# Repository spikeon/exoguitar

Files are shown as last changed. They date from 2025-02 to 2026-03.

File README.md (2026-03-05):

# ExoGuitar
This is the Repo for the ExoGuitar project

> **Note:** The file `README.md` in the repo root is **generated** from this template by `npm run generate-json-files`. Do not edit `README.md` by hand—edit `README.template.md` and the script will regenerate the links section.

## Documentation

- [Assembly Documentation](./ASSEMBLY.md)
- [How to Contribute](./CONTRIBUTING.md)

## MakerWorld Listings

This is a MakerWorld exclusive project; so all print profiles are hosted and maintained there.

[MakerWorld Collection](https://makerworld.com/en/collections/4170197-exoguitar)

## Makerworld Links 

### Back

- Generator - Coming soon to MakerWorld!
- Screw On - Coming soon to MakerWorld!
- Slide In - Coming soon to MakerWorld!

### Bridge

- [Alnicov 6 Strings Saddle Headless](https://makerworld.com/en/models/946216-exoguitar-bridge-alnicov-saddle-headless)
- [Bearing Bridge](https://makerworld.com/en/models/969432-exoguitar-bearing-bridge)
- [Headless Bridge Plate](https://makerworld.com/en/models/988538-exoguitar-headless-bridge-plate)
- OVSAL Headless Bridge Plate - Coming soon to MakerWorld!
- Telecaster Plate - Coming soon to MakerWorld!
- Thru-Body Bridge Plate - Bearing Bridge - Coming soon to MakerWorld!
- Thru-Body Bridge Plate - Tune-O-matic - Coming soon to MakerWorld!
- [Tremelo](https://makerworld.com/en/models/1288644)
- [Tune O' Matic - Multi Plate](https://makerworld.com/en/models/1288679-exoguitar-saddle-tune-o-matic#profileId-1318404)
- Tune O' Matic - Single Plate - Coming soon to MakerWorld!

### Face Plates

- [Acoustic](https://makerworld.com/en/models/1155233-exoguitar-acoustic-core)
- [Dual Humbucker](https://makerworld.com/en/models/1155233-exoguitar-acoustic-core)
- Dual P90 - Coming soon to MakerWorld!
- [Single Humbucker - Bridge](https://makerworld.com/en/models/1155233-exoguitar-acoustic-core)
- [Single Humbucker - Centered](https://makerworld.com/en/models/1155233-exoguitar-acoustic-core)
- [SSS](https://makerworld.com/en/models/1155233-exoguitar-acoustic-core)
- [Telecaster](https://makerworld.com/en/models/1155233-exoguitar-acoustic-core)

### Head

- Arasaka - Coming soon to MakerWorld!
- [Arrow](https://makerworld.com/en/models/977949-exoguitar-head)
- [Classical](https://makerworld.com/en/models/1158327-exoguitar-classical-head-printed-tuners)
- [Explorer](https://makerworld.com/en/models/1242688-exoguitar-head-explorer)
- [Firebird](https://makerworld.com/en/models/1242697-exoguitar-head-firebird)
- [Headless](https://makerworld.com/en/models/977972-exoguitar-headless-adjustable-nut)
- Headless - OVSAL String Lock - Coming soon to MakerWorld!
- Headless - String Lock - Coming soon to MakerWorld!
- Headless v2 - Coming soon to MakerWorld!
- [Jack's Son](https://makerworld.com/en/models/1223137-exoguitar-head-jack-s-son)
- [King Paul](https://makerworld.com/en/models/1405761-exoguitar-head-king-paul)
- [Less Paul](https://makerworld.com/en/models/1242379-exoguitar-head-less-paul)
- Loop - Coming soon to MakerWorld!
- Sharky - Coming soon to MakerWorld!

### Neck

- Neck v3 - Coming soon to MakerWorld!

### Nut

### Shoulders

- Double Cut - Coming soon to MakerWorld!
- Single Cut - Coming soon to MakerWorld!

### Wing Sets

- Arasaka - Coming soon to MakerWorld!
- [BanjNo](https://makerworld.com/en/models/1158493-exoguitar-wings-banj-no)
- CigTar - Coming soon to MakerWorld!
- [Cyber Butterfly](https://makerworld.com/en/models/946179-exoguitar-cyber-butterfly-wings)
- Explorer - Coming soon to MakerWorld!
- [Firebird](https://makerworld.com/en/models/988586-exoguitar-wings-firebird)
- Heart - Coming soon to MakerWorld!
- Ichiban Ezu - Coming soon to MakerWorld!
- Jack's Son - Coming soon to MakerWorld!
- [Kumiko](https://makerworld.com/en/models/1517226-exoguitar-wings-kumiko)
- [Less Paul](https://makerworld.com/en/models/1158385-exoguitar-wings-less-paul)
- [More Paul](https://makerworld.com/en/models/1162982-exoguitar-wings-more-paul)
- MultiBoard - Coming soon to MakerWorld!
- Plastic X - Coming soon to MakerWorld!
- Portal - Coming soon to MakerWorld!
- [Rich](https://makerworld.com/en/models/1078060-exoguitar-wings-rich)
- Symmertrical Guitar - Coming soon to MakerWorld!
- Training-V - Coming soon to MakerWorld!
- Venom - Coming soon to MakerWorld!
- [Warlock](https://makerworld.com/en/models/1391383-exoguitar-wing-set-warlock)

## Multi-Neck Configuration

The sides of the core are made out of 2020 aluminum extrusion and the core terminates exactly along the edge of it.  It was not intended from the beginning, but it DOES allow you to swap out the 2020 for 2040 aluminum extrusion to attach 2 or more cores together to create multiple neck guitars. 

I haven't made a Wing Set specifically for this purpose yet, but the BC Rich may be a good fit for it.  

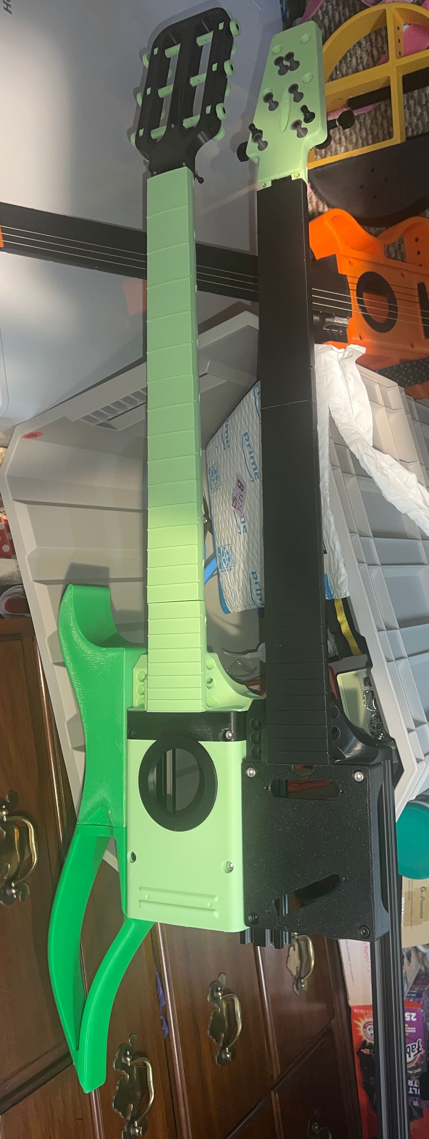
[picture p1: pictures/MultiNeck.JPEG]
Proof of Concept


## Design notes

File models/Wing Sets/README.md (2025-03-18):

# Wing Sets

By default, All wing-sets should only need the hardware listed in the BOM.txt in this folder.  If there is a BOM.txt in the WingSet folder, it is additive to the BOM in this folder.

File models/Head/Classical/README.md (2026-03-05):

# Classical Head

## Plastic Choices

I have now tested this with several types of plastic and can say for certain that you can build functional classical heads out of:
- ABS
- ASA
- PC-ABS
- PLA Tough (at 90% infill and 10 walls)
- PETG-HF (at 90% infill and 10 walls)
- PA

I would still say that you need to be careful regarding the placement of the guitar in relation to the sun if you choose to use PLA Tough or PETG of any form.  

I have had very good results using PLA Tough for the gears.  I did NOT have good results using regular PLA for the gears.  Specifically, I recommend PLA that was made from 3DC870 Resin like [3D Fuel Tough PLA+](https://amzn.to/43JGNtU) for its specific mechanical properties (Special shout out to @nte on the West3D Discord for this).

## To use: 

- Put the string through the hole in the shaft.  If the string can't pass through, loosen the lock knob (the one on the side of the head).  
- Pull the string through the hole until it is taught but not so taught that it could produce a note if plucked.  
- Tighten the Lock Knob until you can no-longer pull or push the string through the hole.  Be careful to not overtighten, as this could lead to the screw cutting the string.  
- Snip off the end of the string.  Do yourself a favor and leave 2-3mm so if you have to remove the string you have a chance of putting it back in. 
- Tighten the tuning knob in the direction that makes the shaft spin so the string wraps over the top of the shaft.  Tighten until the string reaches the desired pitch.  If you are using Nylon Strings, your instrument will not reach a stable tune for a couple of days and you will have to - - repeat this process every few hours; as Nylon Strings have a 2-3 day break in period.  During this time it is important that you tune it every 2-3 hours. 

## Important Note about the printed gears: 

I have decided to deprecate the printed worm gear due to it being too much of a challenge to save $8.

The printed gears are a challenging print and require a 0.2 nozzle.  They are not forgiving.

If you have trouble with the printed gears, you can use [these](https://amzn.to/4l2Nihy) instead.  Glue them to the M2 screw instead of using locktite.  The issue that caused me to remove these from the BOM and design my own printed screws is that the glue doesn't always hold and you may end up having to re-apply glue before you can tune it again, but if for whatever reason you can't get your strings up to tune due to printing defects that'd likely be less of an issue.

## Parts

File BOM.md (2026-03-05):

# Unified BOM

This BOM should contain everything needed to build a single ExoGuitar.  As this will encompass all possible options, there will be left-overs.  If you want to ensure you only buy the necessary parts, feel free to go through each part and compile your own BOM for just the parts you want to build. 

I will first list the items, and then a separate list of links to products, so that I can use bundled items. 

For simplicity, This list only contains suggested hardware.  I will list recommended Guitar Parts at the end, but as they are expensive please make sure that they are part of your build before purchasing.  

## Materials

| Qty | Name |
| :-- | :--- |
| 20  | Screw - Socket Head - M2x6 |
| 6 | Screw - Socket Head - M2x16 |
| 6 | M3 Washer |
| 8 | Screw - Grub - M3x8 |
| 8 | Screw - Flat Head - M3x6 |
| 10  | Screw - Flat Head - M3x10 |
| 10  | Screw - Flat Head - M3x20 |
| 6 | Screw - Flat Head - M3x25 |
| 6 | Screw - Button Head - M3x8 |
| 11  | Screw - Button Head - M3x35 |
| 6 | Screw - Socket Head - M3x10 |
| 5 | Screw - Socket Head - M3x20 |
| 8 | Screw - Socket Head - M3x25 |
| 12  | Screw - Socket Head - M3x40 |
| 2 | Screw - Socket Head - M4x35 |
| 11  | Screw - Button Head - M5x6 |
| 6 | Screw - Button Head - M5x8 |
| 26  | Screw - Button Head - M5x10 |
| 4 | Screw - Button Head - M5x12 |
| 17  | Screw - Button Head - M5x30 |
| 1 | Screw - Socket Head - M5x45 |
| 2 | Screw - Button Head - M6x12 |
| 24  | Nut - Slide In - M3 |
| 60  | Nut - Slide In - M5 |
| 26  | M2x3x3.5 Heat Set Inserts | 
| 2 | M3x4.8x4.6 Flanged Heat Set Inserts |
| 12  | M3x4x4 Heat Set Inserts |
| 49  | M3x4x5 Heat Set Inserts |
| 8 | M4x6x6 Heat Set Inserts | 
| 6 | 3x10x3 V-Bearing |
| 12  | MR128ZZ Bearings |
| 10  | 2mm x 30mm Pin |	
| 10  | 2mm x 60mm Pin |	
| 1 | 2020 Aluminum Extrusion - 500mm |
| 1 | 2020 Aluminum Extrusion - 200mm | 
| 1 | 2020 Aluminum Extrusion - 250mm |
| 1	  | Fret Wire Set |			
| 20  | Prewired SMD Led 0603 |
| 1 | CR2032 Battery | 
| 1	  | 5mmx2mm Slide Switch	| 
| 3	  | Jumper Wire |
| 1	  | CA Glue	|
| 1	  | Super Lube |
| 1 | Locktite Red | 
| 1 | 1m Wire,  24AWG |
| 14  | Screw - Nylon Tipped Set - M3x14 |

## Links

For this list, QTY is the number of the linked product to buy, not the number of individual items needed

### Materials

| Qty | Name | Url | Qty Per Product | Price Per Product | Price  Per Guitar |
| :-- | :--- | :-- | ---: | ---: | ---: |
| 1 | 2020 Aluminum Extrusion - 500mm | [Amazon](https://amzn.to/40dqOAR) | 4 | $30 | $7.50 |
| 1 | 2020 Aluminum Extrusion - 250mm | [Amazon](https://amzn.to/4ig9fHU) | 4 | $16 | $4 |
| 1	  | 2020 Aluminum Extrusion - 200mm | [Amazon](https://amzn.to/4iloM9A) | 4 | $15 | $3.75 |
| 1 | 2mm x 30mm Pin | [Amazon](https://amzn.to/3CVybpb) | 50 | $8.69 | $1.75 |
| 1 | 2mm x 60mm Pin | [Amazon](https://amzn.to/4gU5Ey2) | 50 | $10 | $2 |
| 1 | M3x4.8x4.6 Flanged Heat Set Inserts | [Amazon](https://amzn.to/4kOFT5J) | 20 | $22.86 | $2.29 |
| 1 | M2x3x3.5 Heat Set Inserts | [Amazon](https://amzn.to/4jeeI36) | 110 | $6.59 | $1.56 |
| 1 | M3x4x4 Heat Set Inserts | [Amazon](https://amzn.to/4i5ozHH) | 100 | $7.99 | $0.73 |
| 1 | M3x4x5 Heat Set Inserts | [Amazon](https://amzn.to/4kBjzwc) | 130 | $6.97 | $2.62 |
| 1 | M4x6x6 Heat Set Inserts | [Amazon](https://amzn.to/3WdVVLz) | 110 | $7.99 | $0.58 |
| 1 | Nut - Slide In - M5 | [Amazon](https://amzn.to/4ie0m23) | 100 | $14.59 | $3.50 |
| 1 | Nut - Slide In - M3 | [Amazon](https://amzn.to/3DQQRa3) | 100 | $11.99 | $7.20 |
| 1 | Screw - Socket Head - M2x16 | [Amazon](https://amzn.to/4ij7Lgc) | 100 | $7.16 | $0.42 |
| 1 | Screw - Grub - M3x8 | [Amazon](https://amzn.to/4hqwGht) | 40 | $6.19 | $1.25 |
| 1 | M3 SHCS 6-35 Pack | [Amazon](https://amzn.to/3DBNML3) | N/A | $12.99 | $6.50 |
| 1 | M3 FHCS 4-40 Pack | [Amazon](https://amzn.to/3FM6DDw) | N/A| $18.70 | $9.35 |
| 1 | Screw - Socket Head - M4x35 | [Amazon](https://amzn.to/3DOC3s2) | 50 | $7.68 | $0.30 |
| 1 | Screw - Button Head - M5x6 | [Amazon](https://amzn.to/3FyT36q) | 100 | $8.68 | $0.95 |
| 1 | Screw - Button Head - M5x8 | [Amazon](https://amzn.to/42eKKFG) | 100 | $9.68 | $0.58 |
| 1 | Screw - Button Head - M5x10 | [Amazon](https://amzn.to/41DhzuH) | 100 | $9.96 | $2.60 |
| 1 | Screw - Button Head - M5x30 | [Amazon](https://amzn.to/41upYjY) | 50 | $9.02 | $3.06 |
| 1 | Screw - Socket Head - M5x45 | [Amazon](https://amzn.to/4akIBuH) | 20 | $9.49 | $0.47 |
| 1 | 3x10x3mm V-Bearings | [Amazon](https://amzn.to/4fW4pOq) | 10 | $9.09 | $5.45 |
| 1 | MR128ZZ Bearings | [Amazon](https://amzn.to/3FPtVIE) | 20 | $14.40 | $8.64 |
| 1 | Fret Wire Set | [Amazon](https://amzn.to/4abYcNa) | 1 | $17.49 | $17.49 |
| 1 | Prewired SMD Led 0603 | [Amazon](https://amzn.to/4g1B8SI) | 25 | $13.99 | $11.20 |
| 1 | CA Glue | [Amazon](https://amzn.to/3C5g27S) | N/A | $47.99 | $4.80 |
| 1 | Super Lube | [Amazon](https://amzn.to/3WeCouC) | N/A | $7.97 | $0.80 |
| 1 | CR2032 Battery | [Amazon](https://amzn.to/4aeYF1d) | 4 | $13.19 | $3.30 |
| 1	  | 5mmx2mm Slide Switch | [Amazon](https://amzn.to/4hd0GNI) | 100 | $7.99 | $0.08 |
| 1 | Jumper Wire | [Amazon](https://amzn.to/40c2IXh) | 560 | $9.99 | $0.05 |
| 1 | Locktite Red | [Amazon](https://amzn.to/4iA8NEI) | 100 | $23.20 | $0.23 |
| 1 | Wire | [Amazon](https://amzn.to/41UZiZN) | 91.44 | $26.99 | $0.30 |
| 1 | Screw - Nylon Tipped Set - M3x14 | [Amazon](https://amzn.to/4ecwIJk) | 15 | $8.49 | $0.85 |

#### Totals: 

Before we get to the totals, just a reminder that this document is a One-Size-Fits-All BOM.  If you compiled your own BOM from the individual parts you plan to build with, the price might be far less; depending on the options picked.  In essence, this is the most expensive guitar possible in ExoGuitar.

- Price to buy all of this and build only one: $460
- Price Per Guitar if building many: $120

If we remove the items only needed for the "Luxury features" on the neck (Metal Frets, M2x6 screws, All electronics items from above list) we get a more reasonable result:

- Price to buy all of this and build only one: $370
- Price Per Guitar if building many: $89

### Kits

I currently offer a DIY Kit that includes the above BOM on my Etsy.

[Check it out here!](https://www.etsy.com/listing/4309899889/exoguitar-diy-kit)

I am also in talks with a company about providing these kits for me; which will have a much faster processing time. 

### Hardware

- [Fret Wire Bender](https://amzn.to/3E202E7) - There is a printable one (with its own BOM) in this project [here](./models/Neck/tools/Fret%20Bender/ASSEMBLY.md)
- [Metric Tap Bits](https://amzn.to/41XLL3B)
- [Fanttik E2 Ultra Precision Screwdriver](https://www.amazon.com/dp/B0DSVKLNQR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) - There are a lot of screws in this project.  This helps. 
- [Fanttik T1 Max Soldering Iron](https://www.amazon.com/dp/B0D41ZMDPD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) - This wireless Soldering Iron comes in really handy for soldering parts inside of a guitar. 

### Recommended Guitar Parts
- [Locking Tuning Pegs - 6R](https://amzn.to/4kwxHGX)
- [Locking Tuning Pegs - 3L3R](https://amzn.to/43QKSwm)
- [Single Humbucker Electronics Kit](https://amzn.to/4kV8FkS)
- [Dual Humbucker Electronics Kit](https://amzn.to/4kwyho7)
- [Telecaster Electronics Kit](https://amzn.to/4hj26pr)
- [Tune-O-Matic Bridge](https://amzn.to/4hDBjF1)
- [Piezo Pickups](https://amzn.to/3Xm2SKZ)
- [Nylon Strings](https://amzn.to/3XgaFKf)

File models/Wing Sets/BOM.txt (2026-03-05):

Qty   Name                                 Url                      Optional
  12  Screw - Button Head - M5x10          https://amzn.to/41DhzuH  false
  12  Nut - Slide In - M5                  https://amzn.to/4ie0m23  false
   2  M3x4.8x4.6 Flanged Heat Set Inserts  https://amzn.to/4kOFT5J  false
  10  Screw - Flat Head - M3x10            https://amzn.to/4iCkiM0  false
  10  Screw - Flat Head - M3x20            https://amzn.to/4bVan1y  false
  20  M3x4x5 Heat Set Inserts              https://amzn.to/4kBjzwc  false

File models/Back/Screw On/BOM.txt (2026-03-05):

Qty   Name                      Url                      Optional
   8  Nut - Slide In - M3       https://amzn.to/3DQQRa3  false
   8  Screw - Flat Head - M3x6  https://amzn.to/4bWM7w6  false

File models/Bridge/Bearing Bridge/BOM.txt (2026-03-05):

Qty   Name                         Url                      Optional
   2  M4x6x6 Heat Set Inserts      https://amzn.to/3WdVVLz  false
   5  M3x4x5 Heat Set Inserts      https://amzn.to/4jk12nw  false
   5  Screw - Socket Head - M3x35  https://amzn.to/3C4CAFL  false
   2  Screw - Socket Head - M4x35  https://amzn.to/3DOC3s2  false
   5  Screw - Socket Head - M3x20  https://amzn.to/4gSbS2j  false
   6  Screw - Grub - M3x8          https://amzn.to/4hqwGht  false
   6  3x10x3 V-Bearing             https://amzn.to/4fW4pOq  false
   6  M3x4x5 Heat Set Insert       https://amzn.to/4jk12nw  false
   6  Screw - Button Head - M3x35  https://amzn.to/4a9PA9D  false
   1  Super Lube                   https://amzn.to/3WeCouC  false

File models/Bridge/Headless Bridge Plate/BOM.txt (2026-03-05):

Qty   Name                         Url         Optional
   9  Screw - Button Head - M5x30              false
   9  Nut - Slide In - M5                      false
   6  L Tuning Pegs                            false
  12  Screw - Socket Head - M3x40              false
   6  Screw - Socket Head - M3x10              false
  12  M3x4x5 Heat Set Inserts                  false
   6  M2x3x3 Heat Set Inserts                  false
   2  Screw - Button Head - M5x12              false
   2  Screw - Button Head - M6x12              false

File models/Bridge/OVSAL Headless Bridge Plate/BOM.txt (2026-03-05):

Qty   Name                         Url                      Optional
   1  OVSAL Headless Bridge        https://amzn.to/4navL8k  false
   4  Nut - Slide In - M5          https://amzn.to/3SYdIEF  false
   4  Screw - Socket Head - M5x30  https://amzn.to/3ZFyQDp  false
   4  Screw - Flat Head - M3x16    https://amzn.to/3T1fKnm  false
   4  M3x4x5 Heat Set Inserts      https://amzn.to/45smyBY  false

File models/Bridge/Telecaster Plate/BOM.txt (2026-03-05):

Qty   Name                         Url                      Optional
   1  Telecaster Plate             https://amzn.to/414uZAi  false
   8  Nut - Slide In - M5          https://amzn.to/3SYdIEF  false
   8  Screw - Socket Head - M5x30  https://amzn.to/3ZFyQDp  false
   5  M3x4x5 Heat Set Inserts                               false

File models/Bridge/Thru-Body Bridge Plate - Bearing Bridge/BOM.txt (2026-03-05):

Qty   Name                         Url         Optional
   6  Screw - Button Head - M5x30              false
   6  Nut - Slide In - M5                      false
   6  M4x6x6 Heat Set Insert                   false
   6  M3x4x5 Heat Set Insert                   false

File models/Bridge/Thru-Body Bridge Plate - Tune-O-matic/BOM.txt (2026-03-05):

Qty   Name                         Url                      Optional
   6  Screw - Button Head - M5x30                           false
   6  Nut - Slide In - M5                                   false
   6  M4x6x6 Heat Set Insert                                false
   1  Tune-O-Matic Bridge          https://amzn.to/4hDBjF1  false

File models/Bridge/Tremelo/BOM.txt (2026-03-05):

Qty   Name                         Url                      Optional
   4  Screw - Socket Head - M5x16  https://amzn.to/42s4kyt  false
   4  Screw - Socket Head - M5x30  https://amzn.to/3R20buE  false
   8  Nut - Slide In - M5          https://amzn.to/4hYYDg9  false
   2  M8 Heat Set Inserts          https://amzn.to/3DUSEuV  false
   4  M3x4x5 Heat Set Inserts      https://amzn.to/3YknHHd  false
   1  Tremolo Tailpiece            https://amzn.to/42tQiMK  false
   1  Tune O' Matic Saddle         https://amzn.to/4cgSWJ0  false

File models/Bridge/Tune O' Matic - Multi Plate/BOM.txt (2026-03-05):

Qty   Name                         Url                      Optional
   1  Tune O' Matic Saddle         https://amzn.to/4cgSWJ0  false
   2  M8 Heat Set Inserts          https://amzn.to/3DUSEuV  false
   4  Nut - Slide In - M5          https://amzn.to/4hYYDg9  false
   4  Screw - Socket Head - M5x16  https://amzn.to/42s4kyt  false

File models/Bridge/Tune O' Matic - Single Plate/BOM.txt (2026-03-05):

Qty   Name                         Url                      Optional
   6  Nut - Slide In - M5          https://amzn.to/3SYdIEF  false
   6  Screw - Socket Head - M5x30  https://amzn.to/3ZFyQDp  false
   4  M8 Heat Set Inserts          https://amzn.to/3TV07yg  false

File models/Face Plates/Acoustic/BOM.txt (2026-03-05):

Qty   Name                             Url                      Optional
   1  2020 Aluminum Extrusion - 250mm  https://amzn.to/4ig9fHU  false
   1  2020 Aluminum Extrusion - 200mm  https://amzn.to/4iloM9A  false
   8  Nut - Slide In - M3              https://amzn.to/4i9GfBE  false
   7  Nut - Slide In - M5              https://amzn.to/40tPEOo  false
   3  Screw - Button Head - M5x8       https://amzn.to/4bmHoDI  false
   6  Screw - Button Head - M5x30      https://amzn.to/3D6UoRf  false
   3  Screw - Button Head - M3x8       https://amzn.to/4hWLhlj  false
   6  M3x5x4 Heat Set Inserts          https://amzn.to/4jk12nw  false
   2  Screw - Grub - M3x8              https://amzn.to/3QIKW9T  false
   1  Nylon Strings                    https://amzn.to/3XgaFKf  false
   1  Piezo Pickups                    https://amzn.to/3Xm2SKZ  true
   8  Screw - Flat Head - M3x5         https://amzn.to/43XTCzx  false

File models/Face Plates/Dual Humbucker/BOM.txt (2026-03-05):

Qty   Name                         Url                      Optional
   4  Nut - Slide In - M5          https://amzn.to/4ie0m23  false
   4  Screw - Button Head - M5x30                           false
   1  Electronics Kit                                       false

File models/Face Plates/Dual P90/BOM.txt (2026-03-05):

Qty   Name                         Url                      Optional
   4  Screw - Flat Head - M2.5x45  https://amzn.to/3UN7xnv  false
   4  Nut - Slide In - M5          https://amzn.to/4ie0m23  false
   4  Screw - Button Head - M5x30                           false

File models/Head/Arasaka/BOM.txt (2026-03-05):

Qty   Name                              Url                      Optional
   2  M3x4x5 Heat Set Inserts                                    false
   1  3L3R Tuning Pegs                  https://amzn.to/3Whyrp0  false
   1  Screw - Socket Head - M5x20                                false
   2  Screw - Nylon Tipped Set - M3x14                           false
   1  3mm COB LED lights                https://amzn.to/4kBaCBK  true

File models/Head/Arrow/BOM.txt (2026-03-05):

Qty   Name                         Url                      Optional
   8  M3x4x4 Heat Set Inserts      https://amzn.to/4gSAk3M  false
   1  3L3R Tuning Pegs             https://amzn.to/3Whyrp0  false
   2  Screw - Button Head - M5x12  https://amzn.to/4jeqLxq  false
   1  Screw - Socket Head - M5x45  https://amzn.to/4akIBuH  false
   2  Nut - Slide In - M5          https://amzn.to/40tPEOo  false
   6  Screw - Flat Head - M3x25    https://amzn.to/4acQHW5  false
   2  Screw - Socket Head - M3x25  https://amzn.to/4jePKRd  false
   1  CR2032 Battery               https://amzn.to/4aeYF1d  false
   1  5mmx2mm Slide Switch         https://amzn.to/4hd0GNI  false
   1  Jumper Wire                  https://amzn.to/40c2IXh  false

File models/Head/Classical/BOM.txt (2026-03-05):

Qty   Name                          Url                      Optional
  10  M3x4x4 Heat Set Inserts       https://amzn.to/4gSAk3M  false
   2  Screw - Button Head - M5x12   https://amzn.to/4jeqLxq  false
   1  Screw - Socket Head - M5x45   https://amzn.to/4akIBuH  false
   2  Nut - Slide In - M5           https://amzn.to/40tPEOo  false
   8  Screw - Socket Head - M3x25   https://amzn.to/4jePKRd  false
   6  Screw - Socket Head - M2x20   https://amzn.to/4ij7Lgc  false
   6  M3 Washer                     https://amzn.to/3ETb4fq  false
  12  MR128ZZ Bearings              https://amzn.to/4kudK3t  false
   6  2mmx6mmx8mm Nylon Worm Gears  https://amzn.to/4hxKhD5  false
   6  M2x3x3 Heat Set Inserts       https://amzn.to/4iAqwMw  false

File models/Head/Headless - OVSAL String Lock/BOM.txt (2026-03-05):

Qty   Name                                             Url                      Optional
   1  OVSAL String Lock                                https://amzn.to/4kUiW0v  false
   4  Screw - Flat Head - M3x25                        https://amzn.to/3ZFr24q  false
   6  M3x4x5 Heat Set Inserts https://amzn.to/45smyBY                           false
   2  Screw - Set - M3x16                              https://amzn.to/467d9js  false
   1  Screw - Socket Head - M5x20                      https://amzn.to/4lfbc8V  false

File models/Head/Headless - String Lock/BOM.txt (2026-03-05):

Qty   Name                         Url                                                                                                        Optional
  14  https://amzn.to/4ecwIJk                                                                                                                 false
  14  M3x4x5 Heat Set Inserts      https://amzn.to/45smyBY                                                                                    false
  12  6x2mm Magnets                https://amzn.to/4njDvFh                                                                                    false
   9  BT3x18 Screws                https://us.store.bambulab.com/products/bt3-socket-head-cap-self-tapping-screws-shcs-new?id=42382271774856  false
   1  Screw - Socket Head - M5x20  https://amzn.to/4lfbc8V                                                                                    false

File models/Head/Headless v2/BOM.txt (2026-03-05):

Qty   Name                         Url                                                                                                        Optional
   8  M3x5x3 Heat Set Inserts      https://amzn.to/3IVU5Lx                                                                                    false
   2  Screw - Grub - M3x16         https://amzn.to/4lZ64GS                                                                                    false
   1  BT3x6                        https://us.store.bambulab.com/products/bt3-socket-head-cap-self-tapping-screws-shcs-new?id=42382271578248  false
   2  BT3x20                       https://us.store.bambulab.com/products/bt3-socket-head-cap-self-tapping-screws-shcs-new?id=42382271807624  false
   1  Screw - Button Head - M6x20  https://amzn.to/4l5QsA0                                                                                    false

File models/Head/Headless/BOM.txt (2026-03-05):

Qty   Name                         Url                      Optional
   8  M3x4x4 Heat Set Inserts      https://amzn.to/4gSAk3M  false
   3  Screw - Button Head - M5x6   https://amzn.to/4jeqLxq  false
   1  Screw - Button Head - M5x12  https://amzn.to/4jeqLxq  false
   3  Nut - Slide In - M5          https://amzn.to/40tPEOo  false
   2  Screw - Socket Head - M3x25  https://amzn.to/4jePKRd  false

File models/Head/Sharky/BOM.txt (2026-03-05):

Qty   Name                         Url                      Optional
   3  M3x5x4 Heat Set Inserts      https://amzn.to/4qBGwBF  false
   1  6L Tuning Pegs               https://amzn.to/3N1Ocyq  false
   1  Screw - Socket Head - M6x20  https://amzn.to/4qxr8Gc  false
   2  Screw - Grub - M3x16         https://amzn.to/491vPSP  false

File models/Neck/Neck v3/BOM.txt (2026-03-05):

Qty   Name                         Url                      Optional
   2  M3x500 Threaded Rod          https://amzn.to/4ohOlvJ  false
   2  Nut - Acorn - M3             https://amzn.to/46xpwpl  false
   2  M3x5x4 Heat Set Inserts      https://amzn.to/3IWuQJe  false
   1  Aluminum Extrusion 500mm     https://amzn.to/3IT8tnT  false
  19  Screw - Button Head - M5x10  https://amzn.to/4frELCz  false
  19  Nut - Slide In - M5          https://amzn.to/4oc8uDD  false
  26  10mm rubber bands            https://amzn.to/4pf6Txq  false
   1  Metal Frets 7in Radius       https://amzn.to/4l3akDL  true

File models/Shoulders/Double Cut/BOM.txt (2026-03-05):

Qty   Name                         Url         Optional
   2  Nut - M5                                 false
   5  Nut - Slide In - M5                      false
   7  Screw - Socket Head - M5x35              false
   2  Screw - Button Head - M6x20              false
   1  3x6 Carbon Fiber Bar                     false

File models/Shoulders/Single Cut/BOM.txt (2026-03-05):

Qty   Name                         Url         Optional
   7  Nut - Slide In - M5                      false
   4  Screw - Socket Head - M5x35              false
   3  Screw - Socket Head - M5x16              false
   2  Screw - Button Head - M6x20              false
   1  3x6 Carbon Fiber Bar                     false

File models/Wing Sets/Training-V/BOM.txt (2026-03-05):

Qty   Name                        Url                      Optional
  10  Screw - Socket Head - M5x6  https://amzn.to/3CN3PVy  false
  10  Nut - Slide In - M5         https://amzn.to/3B0aY4b  false
   8  6x3 Magnets                 https://amzn.to/497vUTt  false

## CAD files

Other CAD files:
models/Bridge/Blank/ExoGuitar Main - Bridge - Blank.stl
models/Bridge/Thru-Body Bridge Plate - Tune-O-matic/ExoGuitar Main - Foot - Through Body - M4 Heat Set Inserts.stl
models/Wing Sets/Firebird/Firebird Main - Faceplate - Blank.step
models/Back/Generator/Configurable Back Plate.3mf
models/Back/Slide In/Back Plates.3mf
models/Bridge/Alnicov 6 Strings Saddle Headless/ExoGuitar - Shoe - Through body - Right.step
models/Bridge/Guyker Worm Bridge Plate/Guyker Worm Headless Bridge Plate - Part Studio 1 - Bridge - Worm.3mf
models/Bridge/Headless Bridge Plate/ExoGuitar - Headless Tuner End Cap.step
models/Bridge/Internal Tremelo/Internal Tremolo.step
models/Bridge/OVSAL Headless Bridge Plate/Bridge - OVSAL.3mf
models/Bridge/Telecaster Plate/Telecaster Bridge Plate - Part Studio 1 - Faceplate - Telecaster Plate.3mf
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

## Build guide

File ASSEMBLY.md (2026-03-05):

# Assembly

ExoGuitar is a complicated project.  It has a bunch of hardware and a bunch of different parts.  I hope you can understand how this can make documenting this a challenge, especially for a single person with a full-time job on top of a small business to run.  That being said; there are likely gaps in this documentation.  If you want to assist, it is EXTREMELY welcome for you to reach out. 

## Choosing your parts

Before you start printing an ExoGuitar, you need to decide which kind of guitar you are trying to build.  Do you want an electric or an acoustic?  What body style do you want? Headless or Head?  Printed bridge or one off-the-shelf?

One day I hope I can have the time and resources to build a configurator.  For right now, however, this is a pretty manual process. 

There are 7 main parts that each have their own options:

1. [Shoulder](/models/Shoulders/)
    - [Single Cut](/models/Shoulders/Single%20Cut/)
    - [Double Cut](/models/Shoulders/Double%20Cut/)
2. [Neck](/models/Neck/Neck%20v3/)
3. [Head](/models/Head/)
    - [Classical](/models/Head/Classical/ASSEMBLY.md) - Note: I have only tested this with nylon strings; I make NO promises that it can handle metal strings or the forces that they apply. 
    - [Arrow](/models/Head/Arrow/ASSEMBLY.md)
    - [Explorer](/models/Head/Explorer/ASSEMBLY.md)
    - [Firebird](/models/Head/Firebird/ASSEMBLY.md)
    - [Jack's Son](/models/Head/Jack's%20Son/ASSEMBLY.md)
    - [Less Paul](/models/Head/Less%20Paul/ASSEMBLY.md)
    - [Loop](/models/Head/Loop/ASSEMBLY.md)
    - [Headless](/models/Head/Headless/ASSEMBLY.md)
4. [Bridge](/models/Bridge/)
    - Headless 
        - [Headless for Bearing Bridge](/models/Bridge/Headless%20Bridge%20Plate/ASSEMBLY.md)
        - [Alnicov 6 Strings Saddle Headless](/models/Bridge/Alnicov%206%20Strings%20Saddle%20Headless/ASSEMBLY.md)
    - Head
        - [Thru-Body Bearing Bridge](/models/Bridge/Thru-Body%20Bridge%20Plate%20-%20Bearing%20Bridge/ASSEMBLY.md)
        - [Thru-Body for Tune-o-Matic](/models/Bridge/Thru-Body%20Bridge%20Plate%20-%20Tune-O-matic/ASSEMBLY.md)
        - [Blank](/models/Bridge/Blank/) - Note: this is a starting point for you to model your own bridge
5. [Face Plate](/models/Face%20Plates/)
    - [Acoustic](/models/Face%20Plates/Acoustic/ASSEMBLY.md)
    - [Dual Humbucker](/models/Face%20Plates/Dual%20Humbucker/ASSEMBLY.md)
    - [Single Humbucker](/models/Face%20Plates/Single%20Humbucker/ASSEMBLY.md)
    - [SSS](/models/Face%20Plates/SSS/ASSEMBLY.md)
    - [Telecaster](/models/Face%20Plates/Telecaster/ASSEMBLY.md)
    - [Stealth Plate](/models/Face%20Plates/StealthPlate/ASSEMBLY.md) - Note: This is an experimental face plate that covers the pickups with a thin piece of plastic that you can add decoration to.  It's fun but likely not the best sounding option. 
    - [Clip-in Compartment](/models/Face%20Plates/Clip-In%20Compartment/ASSEMBLY.md) - Note: This is my initial prototype face plate.  It is not recommended unless you want to swap faces often.
6. [Back](/models/Back/)
    Note: The acoustic face plate has its own back as part of its resonance chamber. 
    - [Screw On](/models/Back/Screw%20On/) - Do you want to be able to get to your electronics from the back?  This is the option for you
    - [Slide In](/models/Back/Slide%20In/) - Do you want to glue the back in place and access electronics from the front?  Use this one
7. [Wing Set](/models/Wing%20Sets/)
    The only thing you really need to worry about with the wing sets is if they will work with the shoulder you chose earlier.  
    - Offset Shoulder
        - [Banj-No](/models/Wing%20Sets/BanjNo/)
        - [Less Paul](/models/Wing%20Sets/Less%20Paul/)
        - [More Paul](/models/Wing%20Sets/More%20Paul/)
        - [Warlock](/models/Wing%20Sets/Warlock/)
        - [Explorer](/models/Wing%20Sets/Explorer/)
        - [Firebird](/models/Wing%20Sets/Firebird/)
        - [Rich](/models/Wing%20Sets/Rich/) - Note: Looks the best with the Headless Bridge Plate
        - [Venom](/models/Wing%20Sets/Venom/) - This is the Rich with spider webs in it.
        - [Kumiko](/models/Wing%20Sets/Kumiko/ASSEMBLY.md)
    - Parallel Shoulder
        - [Training-V](/models/Wing%20Sets/Training-V/)
    - Both
        - [Cyber Butterfly](/models/Wing%20Sets/Cyber%20Butterfly/)
8. [Strap](/models/Strap/)
    - [Printed Strap](./models/Strap/Chain%20Link%20Strap/ASSEMBLY.md) - Works but you must be gentle with it; any twisting could break it. 
    - [Nylon Strap](./models/Strap/Nylon%20Strap/ASSEMBLY.md) - Requires a Heavy Duty Sewing Machine
    
## Ordering your Hardware

Once you have picked your parts, get the BOM.txt file from each part and figure out how much of each part you need and then order them.  

## Begin Assembly

### Shoulder

I have found that it's easiest to start with the shoulder and then build out from there.  The first thing I would suggest doing is tapping the ends of all of your 2020 extrusion.  Some 2020 extrusion comes with a 5mm hole and some come with a 6mm hole, so make sure you tap it with the right size.  You will need to tap at least one end of each piece of extrusion depending on the parts you are using.  It may be a good idea to tap all of them; just in case.  

Note for those who have never tapped before:  Use cutting fluid.  Go SLOW.  Like slower than you think.  Go a few turns and then do at least one full rotation backwards, then repeat.  If you're using a drill, make sure to set it to like 6-7 so it won't snap your tap.  

Beyond this, follow the assembly guide in your chosen shoulder and then come back here

### Face Plate

Follow the assembly guide in your chosen face plate, and then come back here

### Bridge 

If you chose to do a Bearing Bridge, follow the assembly documentation in that and then come back here. 

Follow the assembly guide in your chosen bridge plate, then come back here.

### Wing Set

All wing sets follow a certain pattern, so I'll just describe it here in general for now. 
- If you are printing an electric you need to print the solid part with the electronics compartment and assemble that.  If you are printing an acoustic, you can print whatever part you feel makes it look coolest. 
- There should be blank files if you want a different knob / switch / User Interface setup than the one in the standard files. 
- The back of the electronics compartment will be held on by press-insert magnets.  Insert them into the body and then pop a magnet onto the ones you have inserted and then press the back onto those magnets to ensure that you have the correct polarity.  They should be press fit but if that doesn't work you can use super glue to hold them in
- All wing pieces attach to the sides of the 2020 extrusion using M5x10 BHCS bolts and M5 Slide in Nuts.  If there wasn't enough clearance to get a screw driver into the wing to tighten the bolt, a hole should've been added to the outside of the part to allow for access. 
- I recommend putting some super glue between the pieces when you attach them to the 2020 so that you reduce potential rattling or wiggle if any of the screws start to come out over time.
- I recommend when installing the electronics to put a disconnect on all wires going into the electronics compartment so if you need to change the wing set or the face plate you don't have to desolder anything. 
- Some wing sets have parts that are screwed to each other for stability.  See the BOM for the hardware needed for this.  

### Back
 - For the screw on backs, use slide-in nuts and the screws that the back requires to mount them to the 2020 extrusion. 
 - For the slide-in back, put in the pieces making sure that the holes allow access to the sections that need adjustment. 

### Head
- If you are using Nylon Strings, you want the classical Head.  

Follow the assembly guide in your chosen head and then come back here

### Neck
 - Follow the [assembly guide](/models/Neck/Neck%20v3/ASSEMBLY.md) and then come back here. 

### Take a breath
At this point you are done with the ExoGuitar setup for the printed parts; you should have a fully assembled guitar body without any actual guitar parts.  

### Electronics and Strings

Since there are limitless options for electronics, I'm not going to try to describe how to install them all here.  I will say the following, however: 

- When attaching the ground wire that would normally attach to the bridge, if you're using the Bearing Bridge setup you need to attach the ground wire to the Heat Set inserts that the Strings attach to.  You can do this by either soldering wire to the Heat Set Inserts or by using conduictive tape with holes poked in it between the strings and the heat set inserts.  Both of these methods worked well for me.
- I suggest that you add quick-disconnects to all wires running between parts of the guitar, so you can remove those parts without having to remove all the electronics.  This will make maintenance or upgrades MUCH easier.  You'll find that once you build your own guitar you keep wanting to tinker with it. 

For the strings, You will want to use Ball End strings.  Run the strings through the row of 6 heat set inserts, all the way through to the tensioners.  Put on the thickest string first, then run it to the tensioner.  Tighten it just enough that it won't come out on its own, and then slide in your nut plate.  If you are building an acoustic, this is where you will insert your bridge as well.  With all of the pieces in place, now run the rest of your strings.  Tighten them and tune your guitar. 

Now for the fine tuning: 
- Play each string without pressing on any frets.  If you hear any fret-buzz with the string open, you need to raise the strings using the nut using the screws on the back of the head. You will want to lower the nut as much as possible on both sides WITHOUT getting any fret buzz when the strings are open.  
- Play each string at each of the marked frets and listen for fret buzz.  If you have fret buzz at more than one fret, you need to raise the string at the saddle.  If you have fret buzz on only one of the frets (unless it's the last one) then you have a high fret that needs to be sanded down.  Please look up an actual luthier's guide for how to level your frets; but if you're using printed frets know that you need to consider them to be made of paly-dough in comparison to the metal ones so sand / file very lightly.  Once you sand the plastic away you can't put it back. 

For Acoustic core, and want to add Piezo Microphones, follow [these instructions](/models/Face%20Plates/Acoustic/OPTIONAL_ASSEMBLY_PIEZO.md)

Now that you have your electronics installed and your strings are on, plug it into an amp and check that you are getting sound.  If you aren't, check your wires.  I found in my builds that the most likely culprit was the ground wire to the strings.  Once you get sound going, you're done as well!

### Congratulations!
You now have your very own ExoGuitar.   Play it well and know that it's Truly your very own creation!  No-one else on EARTH has the same exact guitar as you; as you picked the colors, plastics, electronics, color patterns, faceplates, wingsets, neck, and head.  You may have even gone the extra mile and glued a hueforge to the front of it!   I hope you enjoy it!

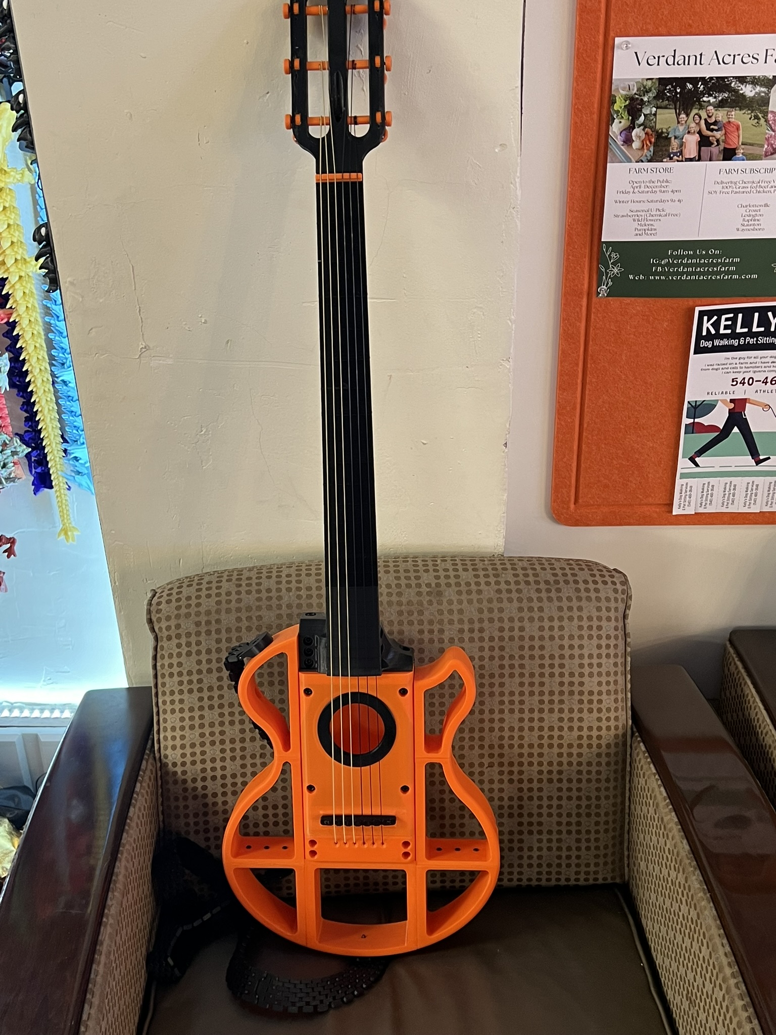
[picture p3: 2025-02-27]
docs/src/pages/Generator/steps/images/accoustic.jpeg

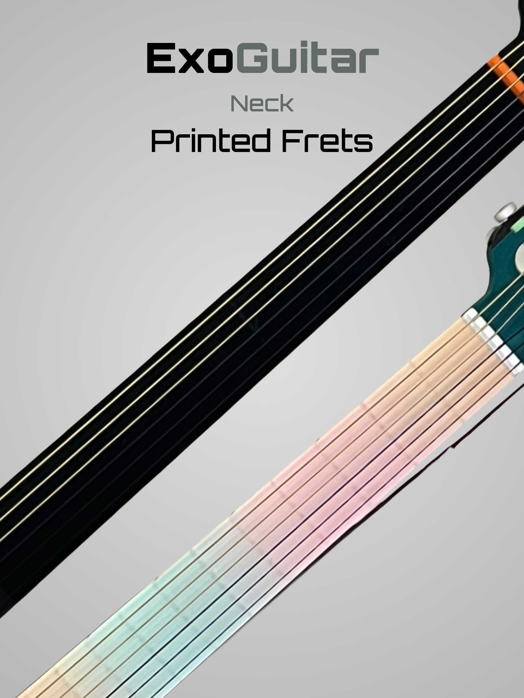
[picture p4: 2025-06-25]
docs/src/pages/Generator/steps/images/printed.png

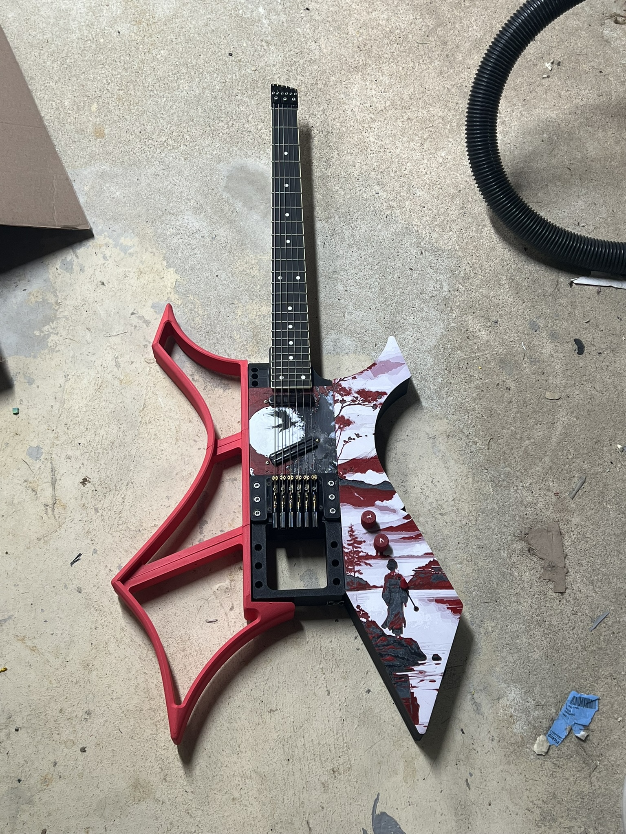
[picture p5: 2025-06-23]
docs/src/pages/Generator/steps/images/wood.jpeg

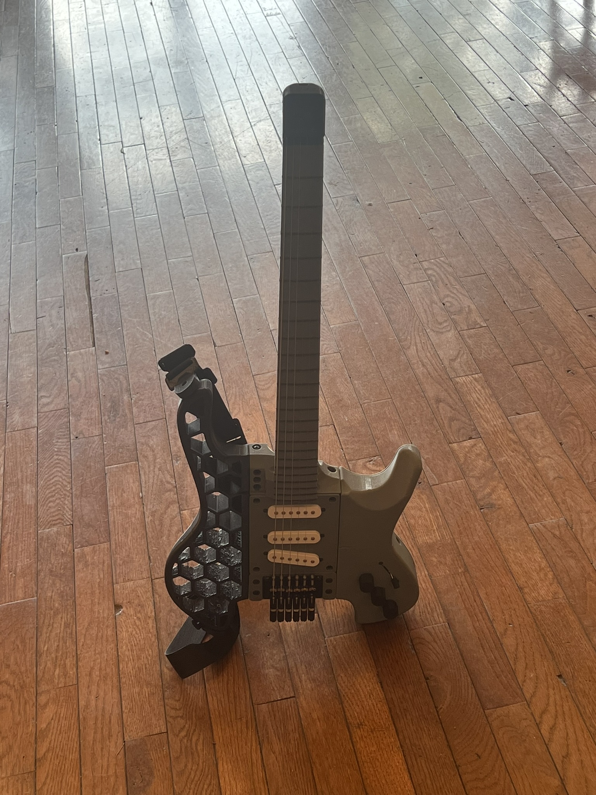
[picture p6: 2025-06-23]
docs/src/pages/Generator/steps/images/electric.jpeg

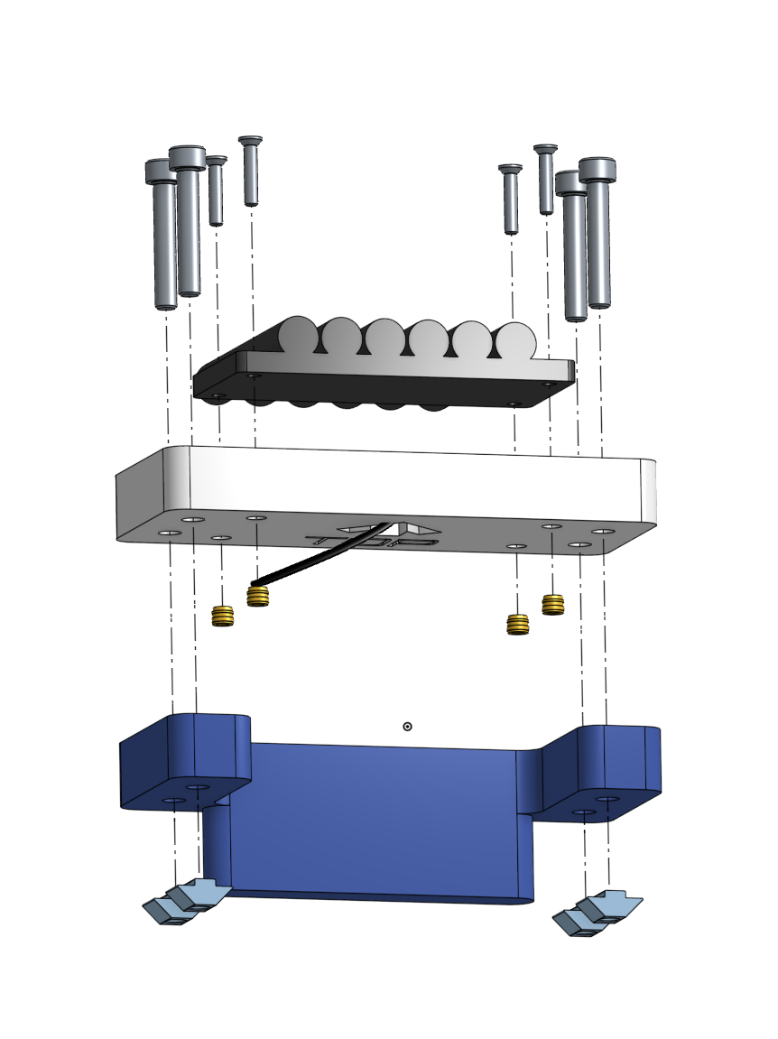
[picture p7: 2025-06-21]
models/Bridge/OVSAL Headless Bridge Plate/exploded views/Full Assembly.png

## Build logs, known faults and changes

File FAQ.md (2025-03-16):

# Frequently Asked Questions

## Does it play?
Yes.

## Do I need any specific Hardware?
Yes.  You will need: 

- A 0.2 nozzle is required for some small gears used in one of the heads.  You will need a M5 or M6 tap depending on what size the hole in your 2020 extrusion is.  

Also, for best results, a printer that can print High-Temp plastics is HIGHLY recommended.  

## What plastic should I use where?

You should print the Core / Neck / Head out of ABS / PC-ABS / ASA.

The gears in the Classical Head's Tuners should use PA / PC / PC-ABS / PLA+ Tough.  Note that this REQUIRES a 0.2mm nozzle so no CF or GF filaments. 

You can print the Wings out of whatever you want.  If you're going to be playing or displaying this anywhere that the Sun can touch this guitar, I recommend NOT using PLA for them.  I make my own using PC-ABS, ABS, and ASA.  Usually Ambrosia from West3D.

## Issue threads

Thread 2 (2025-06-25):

BanjNo Lower wing comfort

NerdBird, 2025-06-25:
The lower wing on the BanjNo has a rather sharp edge where it sits on your lap. Could use a nice rounded edge like the top wing to make it more comfortable to play.

spikeon, 2025-06-25:
This face?

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

spikeon, 2025-06-25:
Well, while I was at it I gave this wing-set a bit of an upgrade:

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

spikeon, 2025-06-25:
Fixed in latest commit

Closed 2025-06-25.

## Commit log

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2025-01-07 Adding updated files. Adding Wall Hanger
    [Wall Hanger and Strap Connector - Secure Cover.step, Wall Hanger and Strap Connector - Strap Mount.step, Wall Hanger and Strap Connector - Wall Mount.3mf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]
2025-01-08 Fixing peg mount holes in Head.
2025-01-08 Splitting up Neck .3mf file, starting work on converting to Bambu .3mf files to upload to MW
    [ExoGuitar - ExoGuitar Neck to Regular Body Adapter.3mf, ExoGuitar - Head - Headless.3mf, ExoGuitar - Head.3mf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]
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2025-01-09 Adding Grub-Screw Version of Bearing Bridge. Adding Bearing Bridge BOM
    [Bearing Bridge - Base.step, Bearing Bridge - Grub Screw.3mf, Bearing Bridge - Rail.step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]
2025-01-09 Changing Bearing Bridge .3mf from Orca to Bambu
    [Bearing Bridge - Grub Screw.3mf]
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2025-01-09 Trimming Photos, Adding links to BOM
    [Bearing Bridge - Grub Screw.3mf]
2025-01-09 Adding Firebird Blank Faceplate
    [Firebird Main - Faceplate - Blank.step]
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2025-01-09 Adding Firebird - Blanks.3mf
    [Firebird.3mf]
2025-01-10 Splitting neck face up into 4 parts, updating .3mf
    [ExoGuitar Neck - Neck - Fretless 1.step, ExoGuitar Neck - Neck - Fretless 2.step, ExoGuitar Neck - Neck - Fretless 3.step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]
2025-01-11 BBL .3mf for Neck
    [ExoGuitar Neck - Neck - Bottom Left - Shouldered.step, ExoGuitar Neck - Neck - Bottom Right - Shouldered.step, ExoGuitar Neck - Neck - Fretless 1.step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]
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2025-01-11 Fixing incorrect sized heat set insert holes on face.
    [ExoGuitar - Neck - Bottom Right - Shouldered.step, ExoGuitar - Neck - Fretless 2.step, ExoGuitar - Neck - Fretless 3.step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]
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2025-01-27 Adding Warlock Hueforge Negative and Fuji Skin
    [ExoGuitar - Warlock - Hueforge Negative.step]
2025-01-29 Adding Fret Bender .3mf
    [ExoGuitar - Neck - Fret Bender.3mf, ExoGuitar - Neck - Frett Press Jig.3mf]
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2025-02-06 Adding Rich Wings .step files and .3mf
    [Classical Head - Printed Tensioners.3mf, ExoGuitar - Neck - Fret Bender.3mf, ExoGuitar - Rich - Bottom Left - Panel.step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]
2025-02-13 Adding Classical Head, Acoustic Body, Banj-No Wings, and Printed Fret Neck
    [BanjNo.3mf, Classical Head - Printed Tensioners.3mf, Classical Neck - Vertical with Printed Frets - Rainbow.3mf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]
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2025-02-20 Adding More Paul. Working on Strap.
    [More Paul - Hollow.3mf, More Paul - Hollow.step, Simple Strap - Adapters - Female Joint to M5.step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]
2025-02-20 Adding supports to one part of More Paul
    [More Paul - Hollow.3mf]
2025-02-20 Renaming More Paul to Less Paul
    [ExoGuitar -Classical Chamber - mini.3mf, Less Paul - Hollow.3mf, Less Paul - Hollow.step]
2025-02-27 Music Instruments Contest Changes
    [Classical Head - Printed Tensioners.3mf, ExoGuitar - Classical Head - TPU Plug.3mf, ExoGuitar -Classical Chamber - mini.3mf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]
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2025-03-03 Updating Head to fix issue
    [Classical Neck - Vertical with Printed Frets - PLA TOUGH.3mf, Classical Neck - Vertical with Printed Frets - Solid Color.3mf, ExoGuitar - Head.3mf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]
2025-03-04 Adding to contributing and assembly. Adding neck template base
    [ExoGuitar - Head - Blank.step, ExoGuitar Main - Neck - 25 Fret - 57mm Wide.stl, Paralell Shoulders.3mf]
2025-03-04 Adding blank ASSEMBLY.md files
    [ExoGuitar - Neck - Fret Press Jig.stl, ExoGuitar - Neck - Frett Press Jig.3mf]
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2025-03-05 Adding assembly for neck
    [Magnet Adapters.step]
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2025-03-05 Adding assembly to classical head
    [Adapters - M3.step, Simple Strap - Chain Strap - Chain Link - Medium.step]
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2025-03-09 Fixing Acoustic Saddle
    [ExoGuitar -Classical Chamber - mini.3mf, ExoGuitar -Classical Chamber.3mf]
2025-03-11 Adding assembly documentation for faceplates
    [ExoGuitar -Classical Chamber.3mf]
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2025-03-11 Missing classical nut
    [Classical Head.3mf, ExoGuitar - Neck - Classical Adjustable Nut.stl]
2025-03-11 Removing deprecated v1 face plates
    [ExoGuitar - Compartment - Stealth Rack.stl, ExoGuitar - Magnetic Compartment - Blank.stl, ExoGuitar - Pickup Rail - x2.stl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]
2025-03-12 Switching from TPU pads to TPU snippets with cutting jig. Adding README documentation about plastic choices for the Classical Head Gears.
    [ExoGuitar - Classical Head - Head - Cover L..stl, ExoGuitar - Classical Head - Head - Cover R..stl, ExoGuitar - Classical Head - TPU Plug.3mf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]
2025-03-14 Fix wide nut orientation. Add Jack's Son
    [ExoGuitar - Classical Nut - 38mm.3mf, ExoGuitar - Nut Plate - Classical - 38mm.step, ExoGuitar - Tuning Peg Gluing Jig.3mf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]
2025-03-14 Fixing Nut
    [ExoGuitar - Classical Nut - 38mm.3mf, ExoGuitar - Nut - Classical - 38mm.step]
2025-03-14 Adding Knobs to GH
    [ExoGuitar+-+Spiral+Dials+and+Switches.3mf, Jack's Son - Hollow.3mf, Knobs (1).3mf]
2025-03-16 Adding Jack's Son's Head
    [Classical Neck - Vertical with Printed Frets - PLA TOUGH.3mf, Classical Neck - Vertical with Printed Frets - Rainbow.3mf, Classical Neck - Vertical with Printe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]
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2025-03-18 Doin' Jack's Son Stuffs
    [Jack's Son.3mf]
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2025-03-22 Changing back to Nylon Work Gears
    [Explorer Head.3mf, Tensioner Gears - 0.2mm.3mf]
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2025-04-05 Tremolo, Bow, Tune O' Matic Madness
    [Guitar Bow.3mf, Loop Head.3mf, Loopl Head.3mf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]
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2025-05-28 Start of speaker wing
    [Speaker - HW-210 - Negative.stl]
2025-05-28 Putting the Cosmetic Bottom back into the ExoGuitar Acoustic Core
    [ExoGuitar -Classical Chamber.3mf]
2025-05-28 Missing bom item
2025-05-28 Add ExoGuitar automation scripts and generated data
    This commit adds automation tooling for the ExoGuitar project:
    ## New Scripts:
    - scripts/generate_json_files.js - Generates JSON data from models directory
    - Creates parts.json (33 parts discovered)
    - Creates unified_bom.json (63 unique BOM items with aggregated quantities)
    - Creates bom.json (part-to-BOM mapping)
    - Copies organized images to docs/public/images/
    - Fixed URL parsing for tab-separated BOM files
    - Handles name normalization for better BOM aggregation
    - scripts/check_missing_docs.js - Documentation completeness checker
    - Scans all parts for BOM.txt and ASSEMBLY.md files
    - Detects empty vs meaningful file conte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
2025-06-02 Adding parts and materials contexts
    [Filament Frets.3mf]
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2025-06-07 Adding neck sanding jig
    [ExoGuitar v2 Neck Sanding Jig.3mf, ExoNeck Jigs - Sanding Jig.step]
2025-06-10 Fixing mistake on Accoustic Core
    [ExoGuitar -Classical Chamber.3mf]
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2025-06-14 Adding a bunch of stuff
    [HexWing.3mf, Kumiko Wings - Right Wing - Bottom - Volume.dxf, Kumiko Wings - Right Wing - Bottom - Blank.dxf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]
2025-06-14 Adding SSS Face Plate
    [ExoGuitar - Face Plate v2 - SSS.3mf, SSS.step]
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2025-06-17 Adding laser cut kumiko and Ichiban Ezu
    [ExoGuitar - Head - Headless.3mf, HexWing.3mf, Ichiban Ezu - Hex Wing - Mini.3mf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]
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2025-06-21 Fixing bom
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2025-06-21 Adding nylon tipped set screws to the Universal BOM
    [ExoGuitar - Face Plate v2 - SSS.3mf, SSS.step]
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2026-03-05 Add Jest tests, refactor generate_json_files, standardize BOM names/URLs, fix Wing Sets meta.json
    Made-with: Cursor
2026-03-05 BOM: Optional column, FHSC fix, aligned columns; AGENTS.md; normalize/format scripts
    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
2026-03-05 Fix GitHub Pages: image base URL, 404 for SPA routes; add Generator tests and CI
    - PartCard & Gallery: prefix image URLs with PUBLIC_URL for /exoguitar base
    - postbuild: copy index.html to 404.html so direct /gallery, /bom links work
    - Add Generator.test.tsx (step flows + BOM assertions), setupTests TextEncoder
    - CI: run docs React tests and generate-json-files
    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
2026-03-05 Markdown audit; remove neck step from generator; include Neck v3 in BOM; move Sanding Jig to Extras
    - Markdown: grammar/typos (ASSEMBLY, BOM, CONTRIBUTING, README), fix internal links, add MARKDOWN_AUDIT.md
    - Generator: remove Neck Type and Neck steps, neckType/neck from state and reducer
    - Summary: always include Neck v3 part in selectedParts and BOM via usePartsContext
    - Delete StepNeckTypes and StepNecks; update Generator tests
    - Move Sanding Jig from models/Neck/Tools to models/Extras
    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
    [ExoGuitar - Sanding Jig.3mf, ExoGuitar - Sanding Jig.step, ExoNeck Jigs - Sanding Jig.step]
2026-03-05 Add markdown-link-check to CI, normalize screw/nut naming, fix MD links
    - Add markdown-link-check devDep, check_links script, and CI step
    - Add .markdown-link-check.json (ignore relative/amzn/makerworld/etsy/localhost)
    - Normalize BOM hardware: Nut - [Type] - M#, Screw - [Type] - M#x#
    - T-nuts normalized as Nut - Slide In - M# (slide-in nuts)
    - Update BOM.md Materials/Links tables to new format
    - Fix Classical README link and MARKDOWN_AUDIT.md
    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
